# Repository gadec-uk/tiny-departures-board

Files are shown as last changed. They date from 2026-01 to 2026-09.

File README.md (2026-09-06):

# tiny-departures-board 

This is an tiny (00 gauge model railway size) live Departures Board replicating those at many UK railway stations (using data provided by National Rail's public API) and UK wide bus stops (using data provided by bustimes.org). This implementation uses a 0.91" OLED display panel with SSD1306 display controller onboard, driven by an ESP32-C3 SuperMini processor board. STL files are also provided for 3D printing the custom case. A small number of pre-assembled departure boards are also available exclusively from our [store](https://store.gadec.co.uk).

This project is based on the table top Departures Board available [here](https://github.com/gadec-uk/departures-board).

A larger LED Matrix departures board project, with audio station announcements, is also available [here](https://github.com/gadec-uk/matrix-departures-board).

## Features
* All processing is done onboard by the ESP32-C3 processor
* Smooth animation matching the real departures boards
* Displays up to the next 9 departures with scheduled time, destination, calling stations and expected departure time
* Optionally only show services calling at a selected railway station
* Optionally only show services departing from selected platform numbers
* Displays Network Rail service messages
* Train information (operator, class, number of coaches etc.)
* In Bus mode, displays up to the next 9 departures with service number, destination and schedule/expected time
* Fully-featured browser based configuration screens - choose any station on the UK rail network / UK Bus Stops
* Automatic firmware updates (optional)
* Displays the weather at the selected location (optional)
* STL files provided for custom 3D printed case





## Quick Start

### What you'll need

1. An ESP32-C3 SuperMini board. For example from [AliExpress](https://www.aliexpress.com/item/1005008809016984.html).
2. A 0.91" 128x32 OLED Display Panel with SSD1306 display controller onboard. For example from [AliExpress](https://www.aliexpress.com/item/1005008640132638.html).
3. A 3D printed case using the [STL](https://github.com/gadec-uk/tiny-departures-board/tree/main/stl) files provided. There are two version of the case - use the deeper version if you have a OLED panel with pre-soldered header pins (and you don't want to remove them). If you don't have a 3D printer, the cases are available from our [store](https://store.gadec.co.uk) or you can use a 3D print service.
4. For National Rail, the board supports using either the Rail Delivery Group feeds (recommended) or the legacy OpenLDBWS feed. Both feeds are free of charge and provide identical information but the legacy OpenLDBWS feed may be discontinued in the future. To use the Rail Delivery Group feeds, you will need a [Live Departure Board 1.1](https://raildata.org.uk/dataProduct/P-d81d6eaf-8060-4467-a339-1c833e50cbbe/overview) consumer key. Alternatively, if you already have a token for the legacy OpenLDBWS feed, you can enter that during setup. The board will only operate in Bus mode without either a Rail Delivery Group consumer key or a legacy OpenLDBWS token.
5. By default, weather data is sourced from Open-Meteo. If you prefer to use OpenWeather (which usually provides slightly more localised weather conditions) you will need an OpenWeather Map API token (these are also free, sign-up for a free developer account [here](https://home.openweathermap.org/users/sign_up)).
6. Some intermediate soldering skills.

A step-by-step guide to obtaining the API keys is available [here](https://departures-board.github.io/Departures-Board-API-Keys-Guide.pdf).



### Wiring Guide

Solder the four wires to the **BACK** of the OLED panel (or directly to the header pins if present). You cannot use Dupont connectors, they will not fit the custom case design. Feed the wires through the opening in the case and down through the post. I recommend that you use 30AWG wires as these will thread easily through the duct in the post. For permanent installations (model railways), rather than using the USBC connection, you can power the SuperMini board directly via its 5V and G connections (you will need a good quality 5V source capable of supplying at least 500mA). Do not connect an external power supply at the same time as using the USBC connector.


### Installing the firmware

The project uses the Arduino framework and the ESP32 v3.3.9 core. If you want to build from source, you'll need [PlatformIO](https://platformio.org).

The easiest way to install the firmware for the first time is to use the online web based installer [here](https://tiny-departures-board.github.io). You will need to use Chrome, Edge or Firefox as your browser as Safari does not support Web Serial.

Alternatively, you can download pre-compiled firmware images from the [releases](https://github.com/gadec-uk/tiny-departures-board/releases). These can be installed over the USB serial connection using [esptool](https://github.com/espressif/esptool). If you have python installed, install with *pip install esptool*. For convenience, a pre-compiled executable version for Windows is included [here](https://github.com/gadec-uk/tiny-departures-board/tree/main/esptool).

Attach the ESP32-C3 SuperMini board via it's USB port and use the following command to flash the firmware:

```
esptool.py --chip esp32c3 --baud 460800 write_flash -z \
  0x0000 bootloader.bin \
  0xe000 boot_app0.bin \
  0x8000 partitions.bin \
  0x10000 firmware.bin
```

The tool should automatically find the correct serial port. If it fails to, you can manually specify the correct port by adding *--port COMx* (replace *COMx* with your actual port, e.g. COM3, /dev/ttyUSB0, etc.).

If using the pre-compiled esptool.exe version on Windows, save the esptool.exe and the four firmware (.bin) files to the same directory. Open a command prompt (Windows Key + R, type cmd and press enter) and change to the directory you saved the files into. Now type the following command on one line and press enter:
```
.\esptool --chip esp32c3 --baud 460800 write_flash -z 0x0000 bootloader.bin 0xe000 boot_app0.bin 0x8000 partitions.bin 0x10000 firmware.bin
```

Subsequent updates can be carried out automatically over-the-air or you can manually update from the Web GUI.

### First time configuration

WiFiManager is used to setup the initial WiFi connection on first boot. The ESP32 will broadcast a temporary WiFi network named "Departures Board", connect to the network and follow the on-screen instructions. You can also watch a video walk-through of setup and configuration process below.

Tiny Departures Board Setup Video (https://youtu.be/3kOFSdS7M2M)

Once the ESP32-C3 has established an Internet connection, the next step is to enter your API keys (if applicable) and then finally, select a station location. Start typing the location name and valid choices will be displayed as you type.

### Web GUI

At start-up, the ESP32's IP address is displayed. To change the station or to configure other miscellaneous settings, open the web page at that address. The settings available are:
- **Board Mode** - switch between National Rail Departures and UK Bus Stops modes
- **Station** - start typing a few characters of a station name and select from the drop-down station picker displayed (National Rail mode).
- **Only show services calling at** - filter services based on *calling at* location (National Rail mode - if you want to see the next trains *to* a particular station).
- **Only show these platforms** - filter services based on the platform they depart from. Note: there are many services for which platform number is not supplied, these would also be filtered out.
- **Bus Stop ATCO code** - type the ATCO number of the bus stop you want to monitor (see [below](#bus-stop-atco-codes) for details).
- **Only show these Bus services** - filter buses by service numbers (enter a list of the service numbers, comma separated).
- **Recently verified ATCO codes** - quickly select from recently used bus stop ATCO codes.
- **Brightness** - adjusts the brightness of the OLED screen.
- **Include current weather at station/bus stop** - optionally display weather conditions at the selected station or bus stop.
- **Include bus replacement services** - optionally include bus replacement services (National Rail mode).
- **Flip the display 180°** - rotates the display (the case design provides two different viewing angles depending on orientation).
- **Set custom hostname for board** - change the hostname from the default "TinyDeparturesBoard", useful if you are running multiple boards.
- **Custom (non-UK) time zone** - if you're not based in the UK you can set the clock to display in your local time zone (see [below](#custom-time-zones) for details).
- **Suppress calling at / info messages** - removes all horizontally scrolling text (much lower functionality but less distracting).
- **Increase Rail API refresh rate** - reduces the interval between data refreshes (National Rail mode). Uses more data and is not usually required.
- **Automatic firmware updates at startup** - automatically checks for AND installs the latest firmware from this repository.
- **Rail data source** - Select which api feed should be used for National Rail mode (only feeds with api keys present are shown).

A drop-down menu (top-right) adds the following options:
- **Check for Updates** - manually checks for and installs any updates to the firmware.
- **Edit API Keys** - view/edit your National Rail and OpenWeather Map API keys.
- **Clear WiFi Settings** - deletes the stored WiFi credentials and restarts in WiFiManager mode (useful to change WiFi network).
- **Restart System** - restarts the ESP32.

#### Other Web GUI Endpoints

A few other urls have been implemented, primarily for debugging/developer use:
- **/factoryreset** - deletes all configuration information, api keys and WiFi credentials. The entire setup process will need to be repeated.
- **/update** - for manual firmware updates. Download the latest binary from the [releases](https://github.com/gadec-uk/departures-board/releases). Only the **firmware.bin** file should be uploaded via */update*. The other .bin files are not used for upgrades. This method is *not* recommended for normal use.
- **/info** - displays some basic information about the current running state.
- **/formatffs** - formats the filing system, erasing the configuration files (but not the WiFi credentials).
- **/dir** - displays a (basic) directory listing of the file system with the ability to view/delete files.
- **/upload** - upload a file to the file system.

### Bus Stop ATCO codes
Every UK bus stop has a unique ATCO code number. To find the ATCO code of the stop you want to monitor, go to [bustimes.org/search](https://bustimes.org/search) and type a location in the search box. Select the location from the list of places shown and then select the particular stop you want from the list. The ATCO code is shown on the stop information page. After entering the code in the Departures Board setup screen, tap the **Verify** button and the location will be shown confirming your selection. You must use the **Verify** button *before* you can save changes. Up to ten of the most recently verified ATCO codes are saved and can be selected from a dropdown list for quick access. The bustimes map and search facility are also embedded in the Bus mode configuration screen.



### Custom Time Zones
To set a custom time zone for the departure board clock, you will need to enter the POSIX time zone string for your location. Some examples are `CST6CDT,M3.2.0/2,M11.1.0/2` for Canada (Central Time) and `AEST-10AEDT,M10.1.0,M4.1.0/3` for Australia (Eastern Time). The easiest way to find the correct syntax is to ask your favourite AI chat engine *"What is the POSIX time zone string for ..."*. Note that changing the time zone only affects the clock (and date) display. Service times are *always* shown in UK time.

### Donating


This software is completely free for non-commercial use without obligation. If you would like to support me and encourage ongoing updates, you can [buy me a coffee!](https://buymeacoffee.com/gadec.uk)

### Licence
This work is licensed under **Creative Commons Attribution-NonCommercial-ShareAlike 4.0**. To view a copy of this licence, visit [https://creativecommons.org/licenses/by-nc-sa/4.0/](https://creativecommons.org/licenses/by-nc-sa/4.0/). Note: the terms of the licence prohibit commercial use of this work, this includes *any* reselling of the work in kit or assembled form for commercial gain.

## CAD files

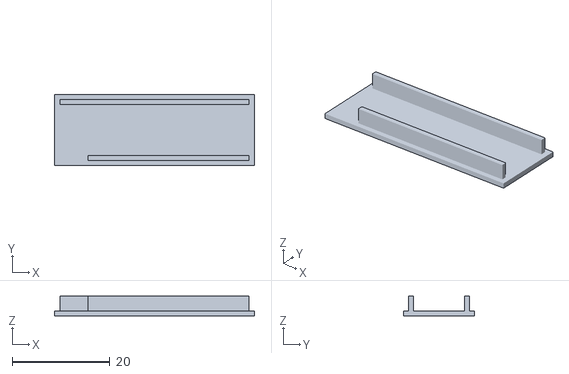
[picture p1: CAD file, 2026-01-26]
stl/Tiny Departure Board Back.stl
41.0 x 14.5 x 4.00

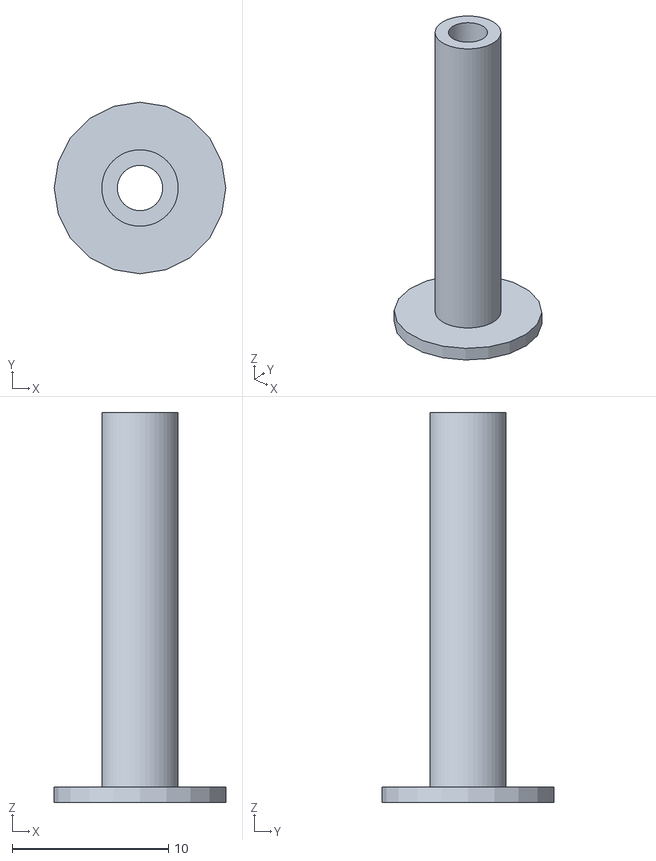
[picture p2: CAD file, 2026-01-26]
stl/Tiny Departure Board Stand.stl
11.0 x 11.0 x 25.0

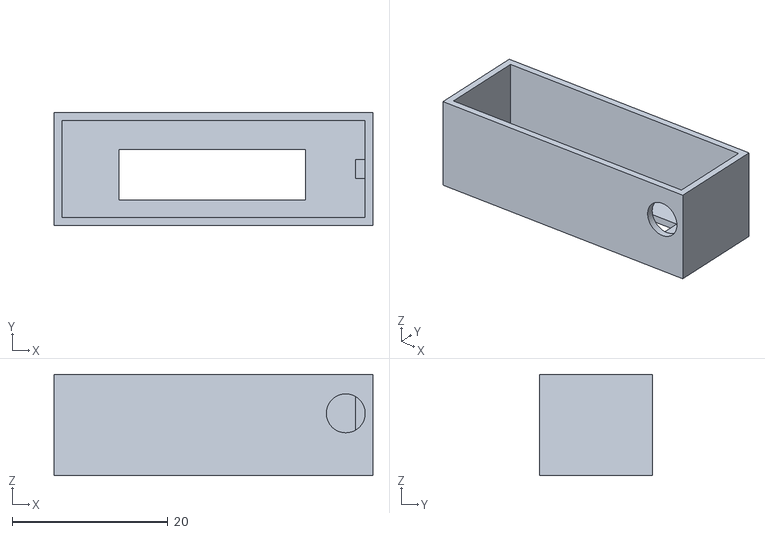
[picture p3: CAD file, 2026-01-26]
stl/Tiny Departure Board Case (Deeper).stl
41.0 x 14.5 x 13.0

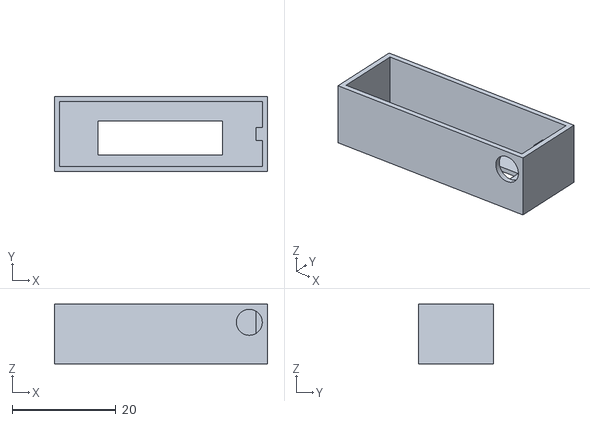
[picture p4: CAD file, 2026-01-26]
stl/Tiny Departure Board Case.stl
41.0 x 14.5 x 11.5

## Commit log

2026-01-26 Initial release commit
    [Tiny Departure Board Back.stl, Tiny Departure Board Case (Deeper).stl, Tiny Departure Board Case.stl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]
2026-07-27 Adds RDG Feed, Web Configuration Upgrade, Open-Meteo client, Bug Fixes
    Version B2.0-W2.0 includes the following changes.
    - Added support for new Rail Data Group feed for National Rail departures.
    - Release notes are now displayed in the web interface following a firmware update.
    - Switched to asynchronous web server for improved GUI performance (particularly on mobile devices).
    - Upgraded web interface to Bootstrap 5 (includes support for "dark mode").
    - Web inteface is now gzipped for performance and space saving.
    - Improves performance of the legacy Darwin Lite data feed.
    - Added Open-Meteo weather client (used if no OpenWeather Map API key is entered).
    - In Bus mode, more data is now re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
2026-08-14 B2.1-W2.0 updates
    - Fixes an issue with the legacy National Rail Darwin client.
    - Other minor bug fixes.

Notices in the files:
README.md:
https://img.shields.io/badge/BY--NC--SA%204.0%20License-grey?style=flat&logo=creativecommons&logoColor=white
